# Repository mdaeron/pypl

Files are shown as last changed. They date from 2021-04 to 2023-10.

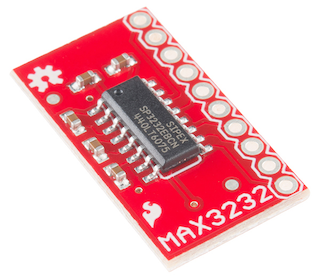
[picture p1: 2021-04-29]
pictures/sparkfun_11189.png

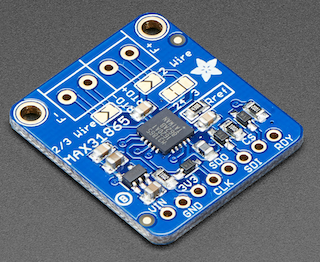
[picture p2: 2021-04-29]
pictures/adafruit_3328.png

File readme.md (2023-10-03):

# Python Prep Line (PyPL)

An open source / open hardware automation system. Originally designed for processing geochemichal samples in our stable isotope lab, but the system is flexible enough to fit many other needs.

## Core design

* Microcontrollers are not encumbered by a full OS, yet can reliably run simple tasks with low latency (μs to ms).
* PyPL uses a *pyboard*, a microcontroller running MicroPython (a full-featured Python implementation running on “bare metal”) to communicate asynchronously with sensors
(T, P, H), and actuators (stepper motors, relays, valves, heating elements...).
* The board is also connected to a full-fledged computer (e.g., a Raspberry Pi or something more expensive) which provides a GUI and logs/syncs/backups data.
* PyPL mostly uses cheap (2–20 €) breakout boards for electronic components, making most repairs plug-and-play. These boards are cheap enough that you can have spare ones, further simplifying hardware maintenance.
* All code, whether on the pyboard or on the computer, is regular Python, promoting painless
development, rapid iteration, and future-proof code.

## Documentation

Full documentation (work in progress) is [here](https://mdaeron.github.io/pypl/).

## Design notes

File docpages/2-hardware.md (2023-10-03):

# Hardware components

### Motherboard

motherboard

A custom PCB connects the [pyboard](https://store.micropython.org/product/PYBv1.1) microcontroller running [micropython](https://docs.micropython.org/en/latest/index.html) to the other electronic components, with the following inputs/outputs:

* fuse-protected DC input (typically 9-24 VDC)
* USB input/output
* 4 general-purpose inputs/outputs (GPIO labeled `X21`, `X22`, `A13`, `A14`) which may be used  for basic two-way communication with external systems (e.g, a mass spectrometer)
* 4 [D-SUB](https://en.wikipedia.org/wiki/D-subminiature) connectors for [RS-232](https://en.wikipedia.org/wiki/RS-232) communication
* 6 screw terminal groups for temperature sensors
* 38 terminal groups for DC relays, six of which can be configured for pulse-width modulation (PWM) operation and are thus well-suited for PID control
* 2 bipolar stepper motor drivers

### Pyboard

pyboard

The brains of the operation is a pyboard (v.1.1, documentation [here](https://docs.micropython.org/en/latest/pyboard/quickref.html)), based on a 168 MHz Cortex M4 CPU.

Note that the maximum total current out of the 3.3V output pins of the pyboard is 250 mA (see [here](https://forum.micropython.org/viewtopic.php?t=9329) for a more complete discussion).

### Stepper Motor Driver Boards

pololu_mp6500

We use a breakout board for the MPS MP6500 microstepping bipolar [stepper motor](https://en.wikipedia.org/wiki/Stepper_motor) driver from Pololu (docs [here](https://www.pololu.com/product/2966)). Rotating the motor is achieved by repeatedly switching the STEP pin between high and low. The motherboard is configured by default for 1/8 step resolution (pins MS1 and MS2 high, i.e. set to +3.3 V), but full steps, half-steps and quarter-steps can be selected using different MS1 and MS2 settings, either by modifying the motherboard or by tinkering with the stepper driver board.

These driver boards work well but are easy to fry when mishandled. Never connect or disconnect motor wires while the driver board is powered.

### Temperature Readings

Up to 4 independent temperature reading. Each reading may come from either:

* a [thermocouple](https://en.wikipedia.org/wiki/Thermocouple) connected to a MAX31856 chip
* a [resistance temperature detector](https://en.wikipedia.org/wiki/Resistance_thermometer) (PT1000 or PT100) connected to a MAX31865 chip

#### Thermocouple Board

* [Adafruit 3263](https://www.adafruit.com/product/3263)
* Based on MAX31856
* Configured for continuous readings and no averaging; with these settings the IC automatically measures T every 100 ms or so (82 ms in our tests) with measurement noise on the order of 0.05 °C.
* Reading the latest measurements using SPI is much faster (only about 0.14 ms when tested using a baudrate of 1e7).
* Maximum current used by each MAX31856 is 2 mA.

adafruit_3263

#### PT1000 Board

* [Adafruit 3328](https://www.adafruit.com/product/3328)
* Based on MAX31865

adafruit_3328

#### Thermocouples (type K)

* Supplier: https://www.prosensor.fr
* Part #: K4051000-2-1/TEF
* OD = 0.5 mm
* L = 1 m

#### Resistance Temperature Detectors  (PT1000)

### Heating Elements
heating_element

* Supplier: https://www.prosensor.fr
* Part #: CCHC-1/4-11/4-300-0 or CCHC-6.5-30-300-0
* 300 W at 230 VAC
* OD = 6.35 mm or 6.5 mm
* L = 31.75 mm or 30 mm

These relays are powered by 230 VAC and should thus only be switched using dedicated optocoupler relays (see below). 

### Pressure Readings

#### MicroPirani and DualTrans Vacuum/Pressure Gauges

* Part #: [MKS 925](https://www.mksinst.com/f/925-micro-pirani-vacuum-transducer)
* Part #: [MKS 910](https://www.mksinst.com/f/910-micro-pirani-vacuum-transducer)
* Communicates through an [RS-232](https://en.wikipedia.org/wiki/RS-232) serial connection

mks_910

#### RS232 / TTL Transceiver Board

Converts TTL (Transistor-Transistor Logic) signals to and from [RS-232](https://en.wikipedia.org/wiki/RS-232) signals

* [SparkFun Transceiver Breakout (BOB-11189)](https://www.sparkfun.com/products/11189)
* Based on MAX3232

sparkfun_11189

### Relays

The pyboard communicates through I2C with a GPIO expansion board based on the MCP23017 chip, providing access to 16 input or output ports. Each of these ports is connected to a power MOSFET, providing the ability to quickly switch DC power to 16 screw terminals.

#### 1.7.1 – GPIO Expansion Board

* Based on MCP23017
* All ports are pulled low (connected to ground by 10K resistors).
* As a result, all switches are off by default.

mcp23017

#### Power MOSFETSs

Used to connect screw terminals to ground safely and quickly. This means that when the MOSFET is off, whatever is connected to the screw terminals will float at a moderately high DC voltage (e.g., 24 VDC) despite being powered off, so any electrical connections should be suitably insulated.

#### Optocoupler relays

### Power Supply

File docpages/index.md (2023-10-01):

---
hide:
  - toc
---

# Python Prep Line (PyPL)

An open source, open hardware, automated preparation line for processing geochemical samples. Originally designed for CO<sub>2</sub> samples, but should handle anything which requires:

* switching relays, valves or heating elements
* monitoring temperature sensors (e.g., [thermocouples](https://en.wikipedia.org/wiki/Thermocouple) or [RTD](https://en.wikipedia.org/wiki/Resistance_thermometer) sensors)
* monitoring MKS vacuum/pressure gauges.
* controlling [stepper motors](https://en.wikipedia.org/wiki/Stepper_motor)

The user interface runs on a raspberry pi computer but this computer may be switched off or unplugged without affecting automated processes, which remain running on an independent microcontroller which handles lower-level interaction with sensors and various electronic components.

Modifying hardware configuration and sample preparation protocols is easily done using [Python](https://www.python.org) (on the computer) and [MicroPython](https://micropython.org) (on the microcontroller).

## Contributors

Originally created by [Mathieu Daëron](https://daeron.fr), with advice, contributions and feedback from Samir Kassi, Arnaud Dapoigny, and Justin Chaillot.

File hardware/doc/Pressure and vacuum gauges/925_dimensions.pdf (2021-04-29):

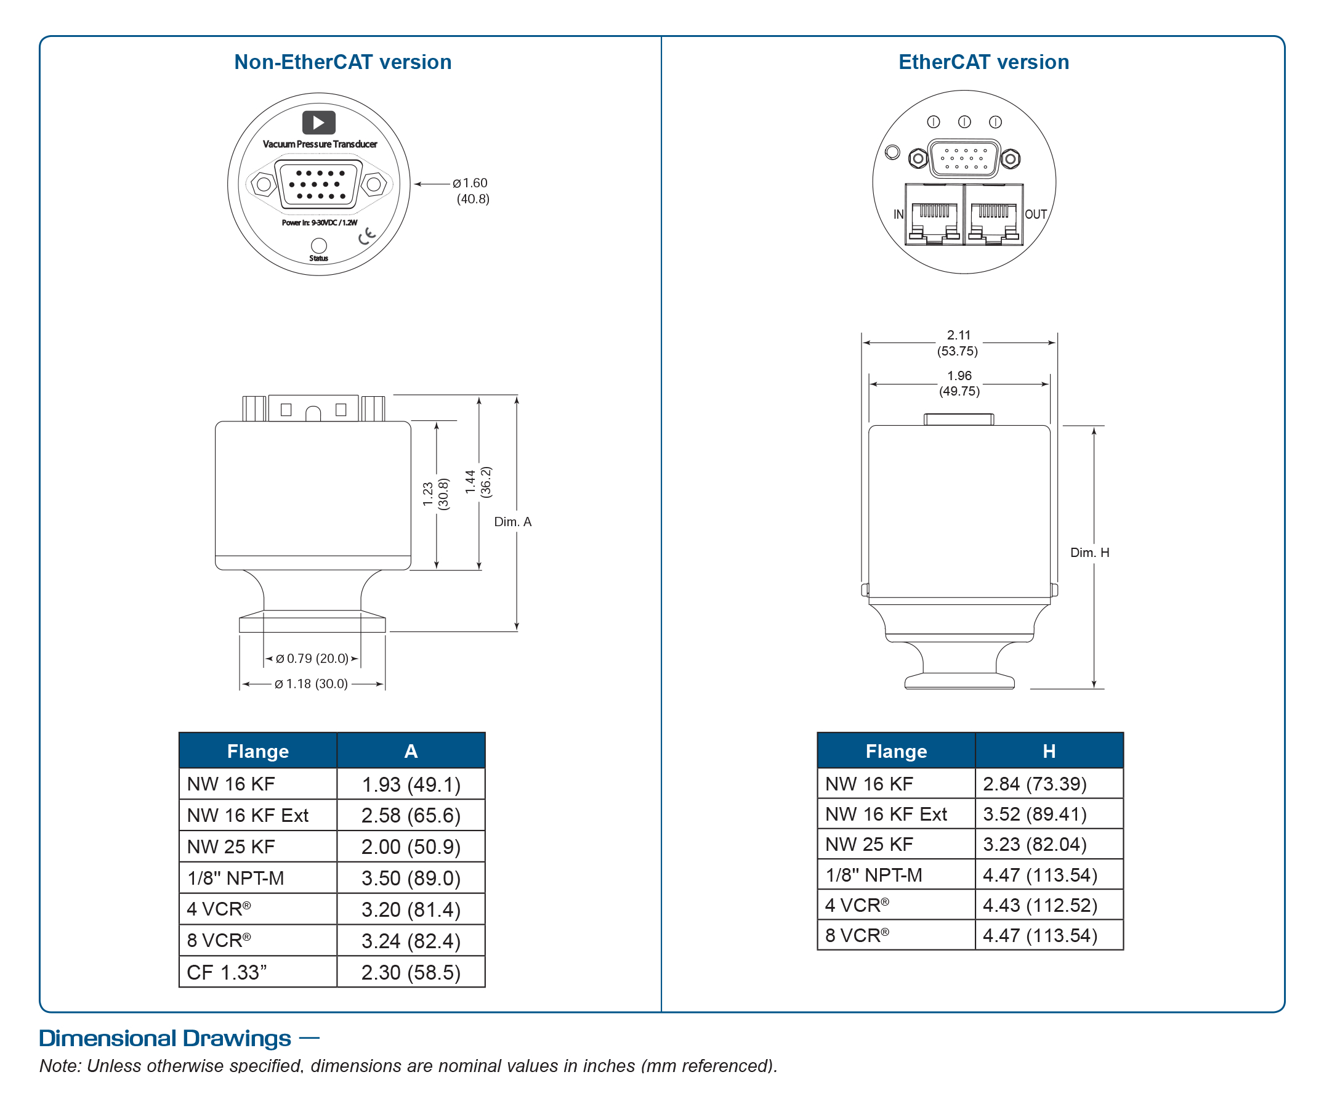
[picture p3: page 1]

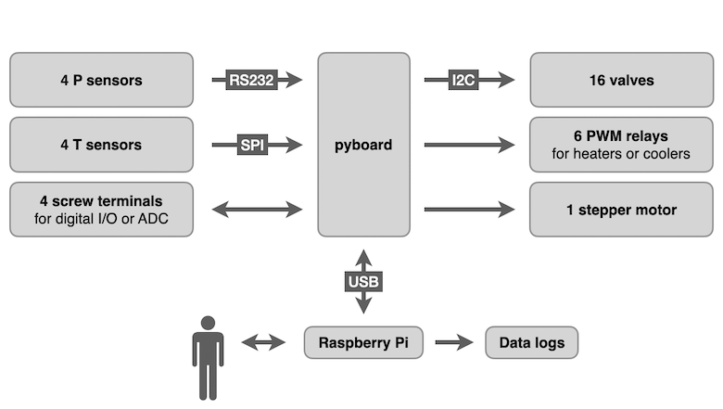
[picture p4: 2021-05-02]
pictures/pypl_schematic.png

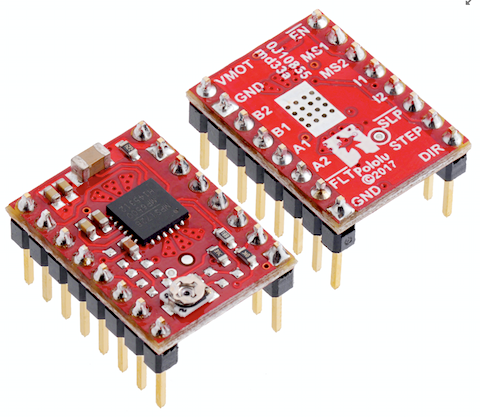
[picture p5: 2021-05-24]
pictures/pololu_mp6500.png

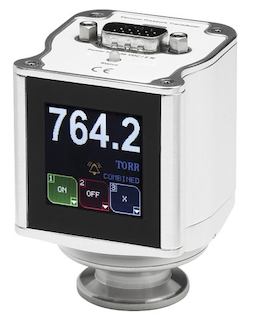
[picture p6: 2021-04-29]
pictures/mks_910.png

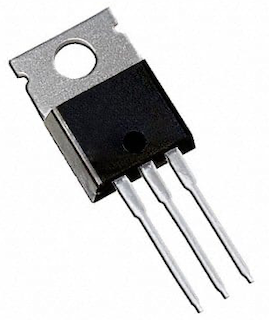
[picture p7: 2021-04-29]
pictures/mosfet.png

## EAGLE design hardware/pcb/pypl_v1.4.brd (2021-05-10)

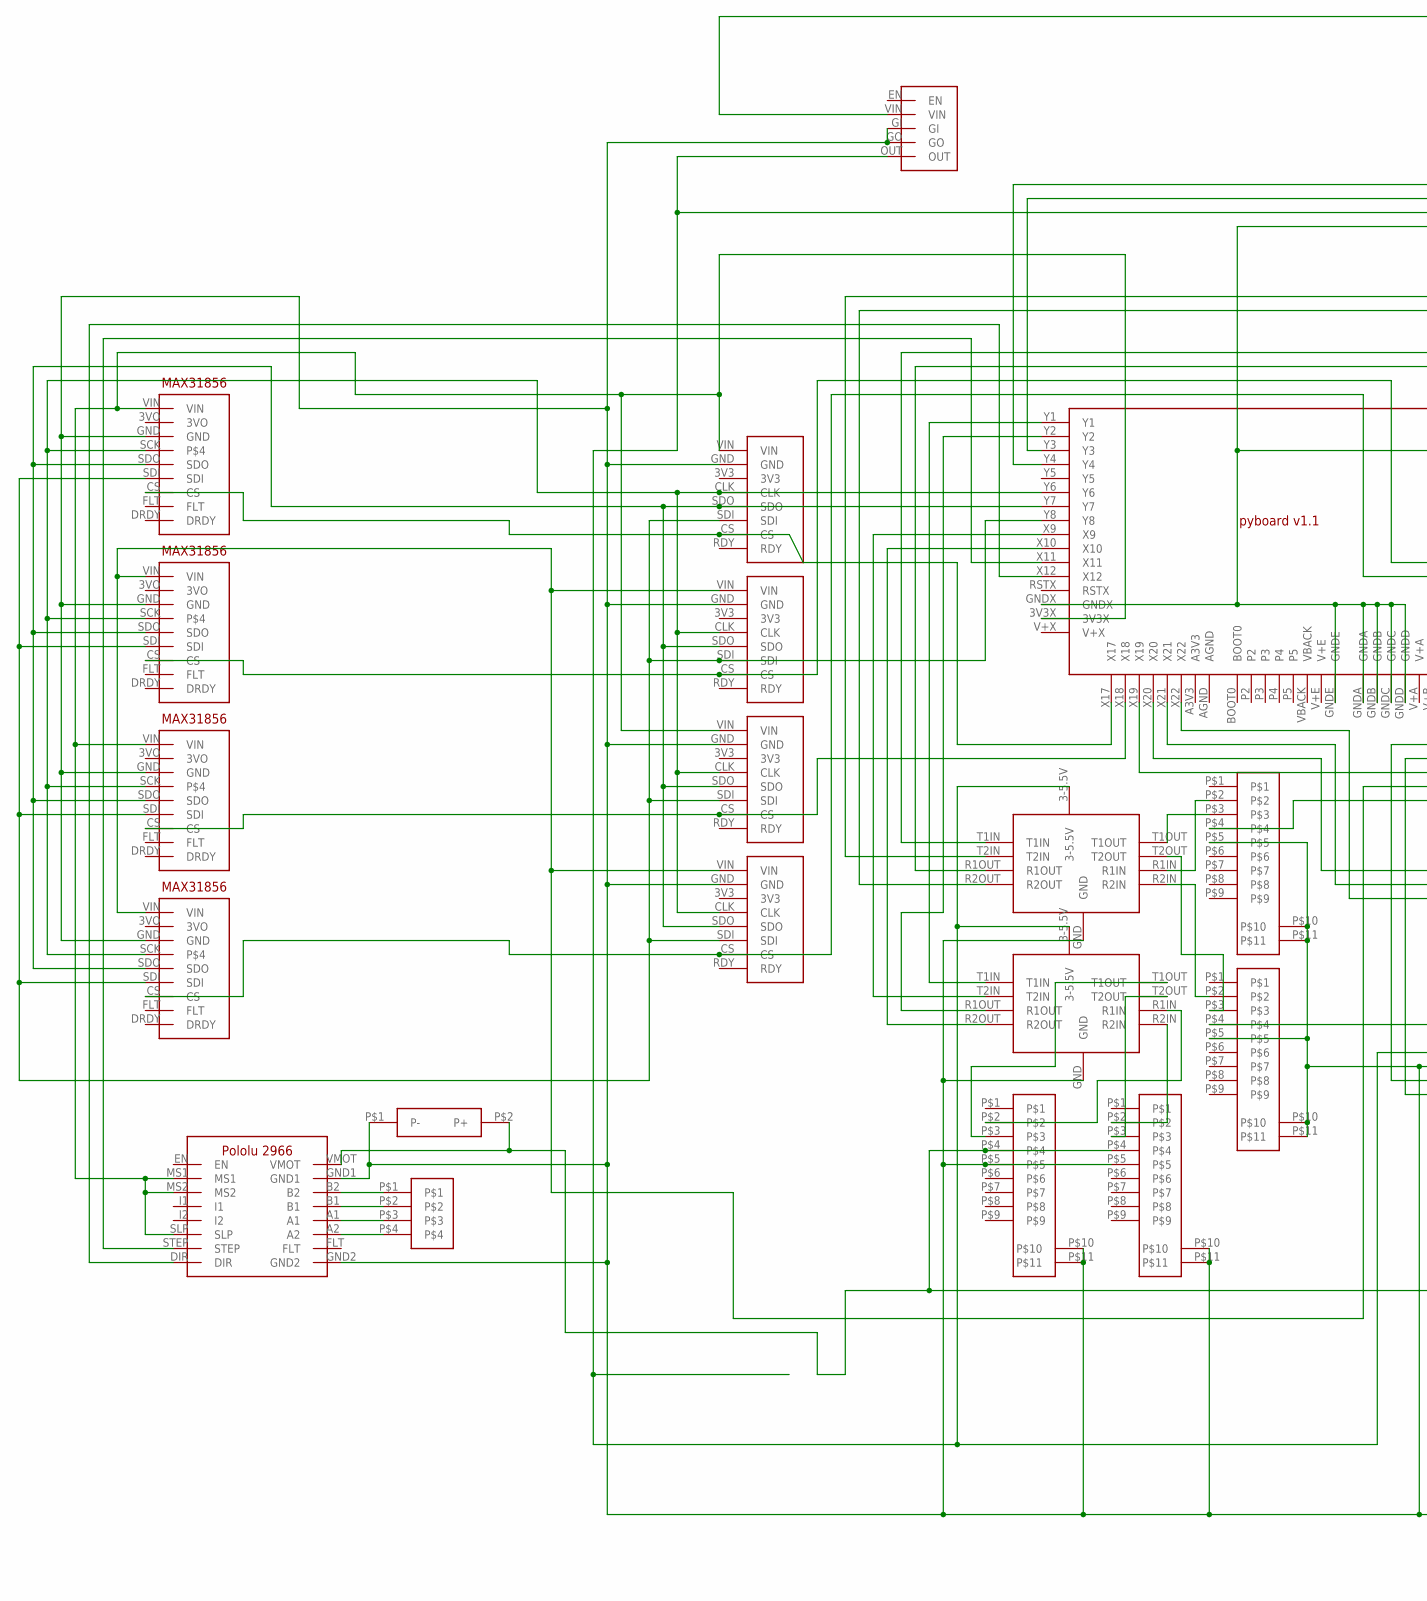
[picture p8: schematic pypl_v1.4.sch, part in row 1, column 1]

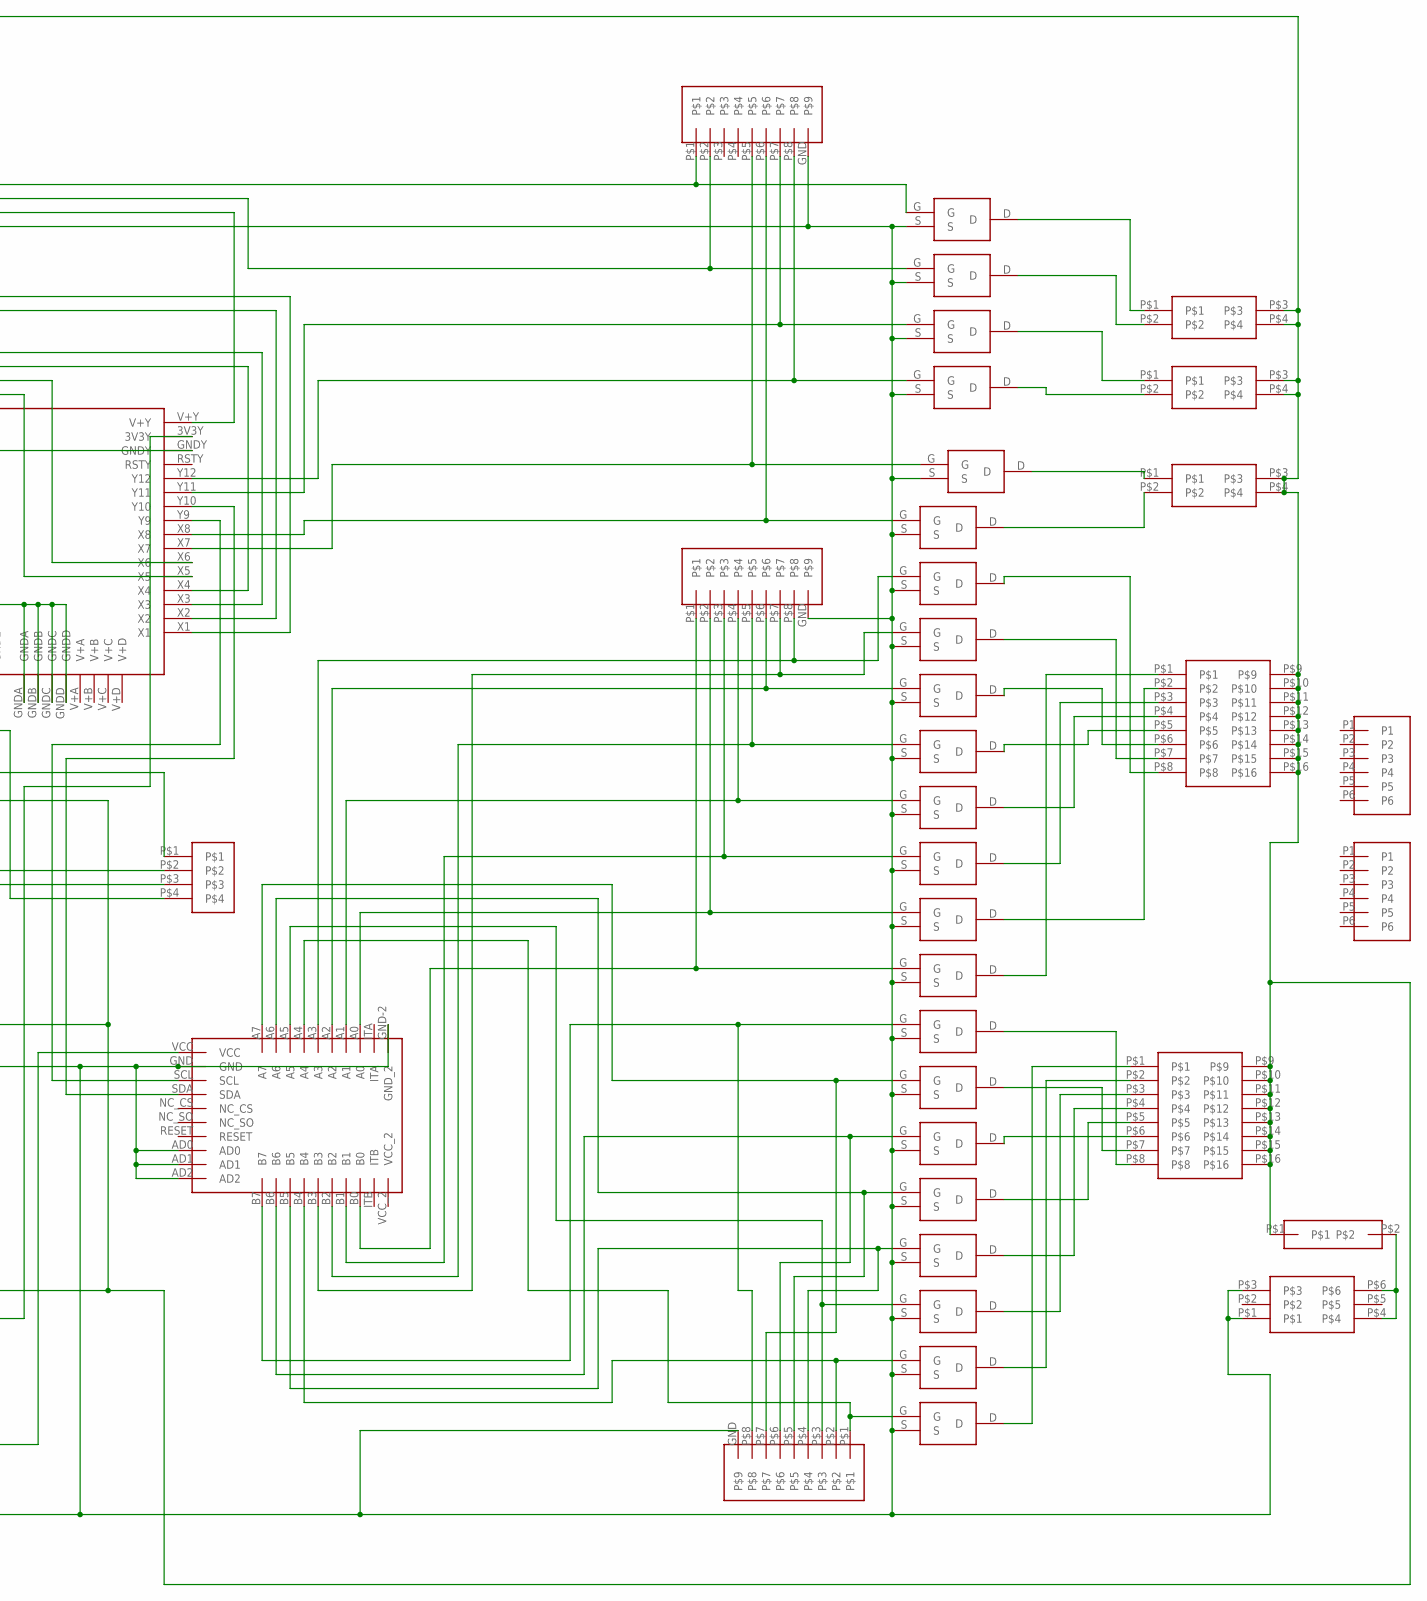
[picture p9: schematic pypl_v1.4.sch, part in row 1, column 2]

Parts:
U$1, U$23, U$25, U$26: MAX31865
U$2, U$3, U$4, U$5, U$6, U$7, U$8, U$9, U$11, U$12, U$13, U$14, U$15, U$16, U$17, U$18, U$33, U$34, U$42, U$43, U$44, U$45: IRLB8721PBF
U$10: MCP23017
U$19, U$20, U$21, U$22: DSUB-9
U$24: PYBOARD_V1.1
U$27, U$28: BORNIER_DUPLEX_X16
U$29: CAP-GOTRONIC-04936
U$30, U$46: BORNIER_1X4_2.54
U$31: PORTE-FUSIBLE
U$32: MP6500-2966
U$35, U$40, U$41: BORNIER_DUPLEX_X4
U$36, U$37: BOB-1189; BOB-11189
U$38: MOLEX_MINIFT_JR_ANGLED_X6
U$39: D24V50F5D24V50F5; D24V50F5
U$47, U$48, U$49: RESISTOR_BANK_BUSSED_X8
U$50, U$51, U$52, U$53: MAX31856
U$54, U$55: PINH06

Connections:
GND: U$1.GND, U$2.S, U$3.S, U$4.S, U$5.S, U$6.S, U$7.S, U$8.S, U$9.S, U$10.AD0, U$10.AD1, U$10.AD2, U$10.GND, U$10.GND-2 (GND_2), U$11.S, U$12.S, U$13.S, U$14.S, U$15.S, U$16.S, U$17.S, U$18.S, U$19.P$5, U$19.P$10, U$19.P$11, U$20.P$5, U$20.P$10, U$20.P$11, U$21.P$5, U$21.P$10, U$21.P$11, U$22.P$5, U$22.P$10, U$22.P$11, U$23.GND, U$24.GNDA, U$24.GNDB, U$24.GNDC, U$24.GNDD, U$24.GNDE, U$24.GNDX, U$24.GNDY, U$25.GND, U$26.GND, U$29.P$1 (P-), U$32.GND1, U$32.GND2, U$33.S, U$34.S, U$36.GND, U$37.GND, U$38.P$1, U$38.P$3, U$39.GI, U$39.GO, U$42.S, U$43.S, U$44.S, U$45.S, U$47.GND, U$48.GND, U$49.GND, U$50.GND, U$51.GND, U$52.GND, U$53.GND
unnamed: U$24.X12, U$32.DIR
unnamed: U$10.SDA, U$24.Y10
unnamed: U$10.SCL, U$24.Y9
unnamed: U$24.X4, U$36.R1OUT
unnamed: U$24.X3, U$36.T1IN
unnamed: U$24.X2, U$36.R2OUT
unnamed: U$24.X1, U$36.T2IN
unnamed: U$24.Y1, U$37.T1IN
unnamed: U$24.Y2, U$37.R1OUT
unnamed: U$24.X10, U$37.R2OUT
unnamed: U$24.X9, U$37.T2IN
unnamed: U$1.CLK, U$23.CLK, U$24.Y6, U$25.CLK, U$26.CLK, U$50.SCK, U$51.SCK, U$52.SCK, U$53.SCK
unnamed: U$1.SDO, U$23.SDO, U$24.Y7, U$25.SDO, U$26.SDO, U$50.SDO, U$51.SDO, U$52.SDO, U$53.SDO
unnamed: U$1.SDI, U$23.SDI, U$24.Y8, U$25.SDI, U$26.SDI, U$50.SDI, U$51.SDI, U$52.SDI, U$53.SDI
unnamed: U$10.A7, U$15.G, U$47.P$7
unnamed: U$4.G, U$10.B2, U$48.P$5
unnamed: U$7.G, U$10.A3, U$48.P$8
unnamed: U$6.G, U$10.B3, U$48.P$7
unnamed: U$5.G, U$10.A2, U$48.P$6
unnamed: U$3.G, U$10.A1, U$48.P$4
unnamed: U$2.G, U$10.B1, U$48.P$3
unnamed: U$8.G, U$10.A0, U$48.P$2
unnamed: U$9.G, U$10.B0, U$48.P$1
unnamed: U$10.B4, U$17.G, U$47.P$2
unnamed: U$10.B5, U$12.G, U$47.P$4
unnamed: U$10.B6, U$14.G, U$47.P$6
unnamed: U$10.B7, U$16.G, U$47.P$8
unnamed: U$10.A6, U$13.G, U$47.P$5
unnamed: U$7.D, U$28.P$8
unnamed: U$6.D, U$28.P$7
unnamed: U$5.D, U$28.P$6
unnamed: U$30.P$1, U$32.B2
unnamed: U$16.D, U$27.P$8
unnamed: U$15.D, U$27.P$7
unnamed: U$4.D, U$28.P$5
unnamed: U$3.D, U$28.P$4
unnamed: U$2.D, U$28.P$3
unnamed: U$8.D, U$28.P$2
unnamed: U$9.D, U$28.P$1
unnamed: U$14.D, U$27.P$6
unnamed: U$13.D, U$27.P$5
unnamed: U$12.D, U$27.P$4
unnamed: U$11.D, U$27.P$3
unnamed: U$17.D, U$27.P$2
unnamed: U$18.D, U$27.P$1
unnamed: U$24.X19, U$46.P$1
unnamed: U$40.P$2, U$42.D
unnamed: U$10.VCC, U$24.V+Y, U$36.3-5.5V, U$37.3-5.5V, U$39.OUT
unnamed: U$31.P$2, U$38.P$4, U$38.P$6
unnamed: U$24.X6, U$26.CS, U$51.CS
unnamed: U$1.CS, U$24.X18, U$52.CS
unnamed: U$24.X17, U$25.CS, U$50.CS
unnamed: U$24.X7, U$34.G, U$49.P$5
unnamed: U$24.X8, U$33.G, U$49.P$6
unnamed: U$33.D, U$35.P$2
unnamed: U$34.D, U$35.P$1
unnamed: U$30.P$2, U$32.B1
unnamed: U$30.P$3, U$32.A1
unnamed: U$30.P$4, U$32.A2
unnamed: U$19.P$2, U$36.R1IN
unnamed: U$20.P$2, U$36.R2IN
unnamed: U$40.P$1, U$43.D
unnamed: U$21.P$2, U$37.R2IN
unnamed: U$22.P$2, U$37.R1IN
unnamed: U$19.P$3, U$36.T1OUT
unnamed: U$20.P$3, U$36.T2OUT
unnamed: U$22.P$3, U$37.T1OUT
unnamed: U$21.P$3, U$37.T2OUT
unnamed: U$1.VIN, U$24.3V3X, U$25.VIN, U$32.MS1, U$32.MS2, U$32.SLP, U$50.VIN, U$52.VIN
unnamed: U$23.CS, U$24.X5, U$53.CS
unnamed: U$41.P$2, U$44.D
unnamed: U$23.VIN, U$24.3V3Y, U$26.VIN, U$51.VIN, U$53.VIN
unnamed: U$19.P$4, U$20.P$4, U$21.P$4, U$22.P$4, U$27.P$9, U$27.P$10, U$27.P$11, U$27.P$12, U$27.P$13, U$27.P$14, U$27.P$15, U$27.P$16, U$28.P$9, U$28.P$10, U$28.P$11, U$28.P$12, U$28.P$13, U$28.P$14, U$28.P$15, U$28.P$16, U$29.P$2 (P+), U$31.P$1, U$32.VMOT, U$35.P$3, U$35.P$4, U$39.VIN, U$40.P$3, U$40.P$4, U$41.P$3, U$41.P$4
unnamed: U$24.X20, U$46.P$2
unnamed: U$24.X21, U$46.P$3
unnamed: U$24.X22, U$46.P$4
unnamed: U$24.X11, U$32.STEP
unnamed: U$10.A5, U$11.G, U$47.P$3
unnamed: U$41.P$1, U$45.D
unnamed: U$24.Y11, U$43.G, U$49.P$7
unnamed: U$24.Y12, U$42.G, U$49.P$8
unnamed: U$24.Y3, U$44.G, U$49.P$2
unnamed: U$24.Y4, U$45.G, U$49.P$1
unnamed: U$10.A4, U$18.G, U$47.P$1

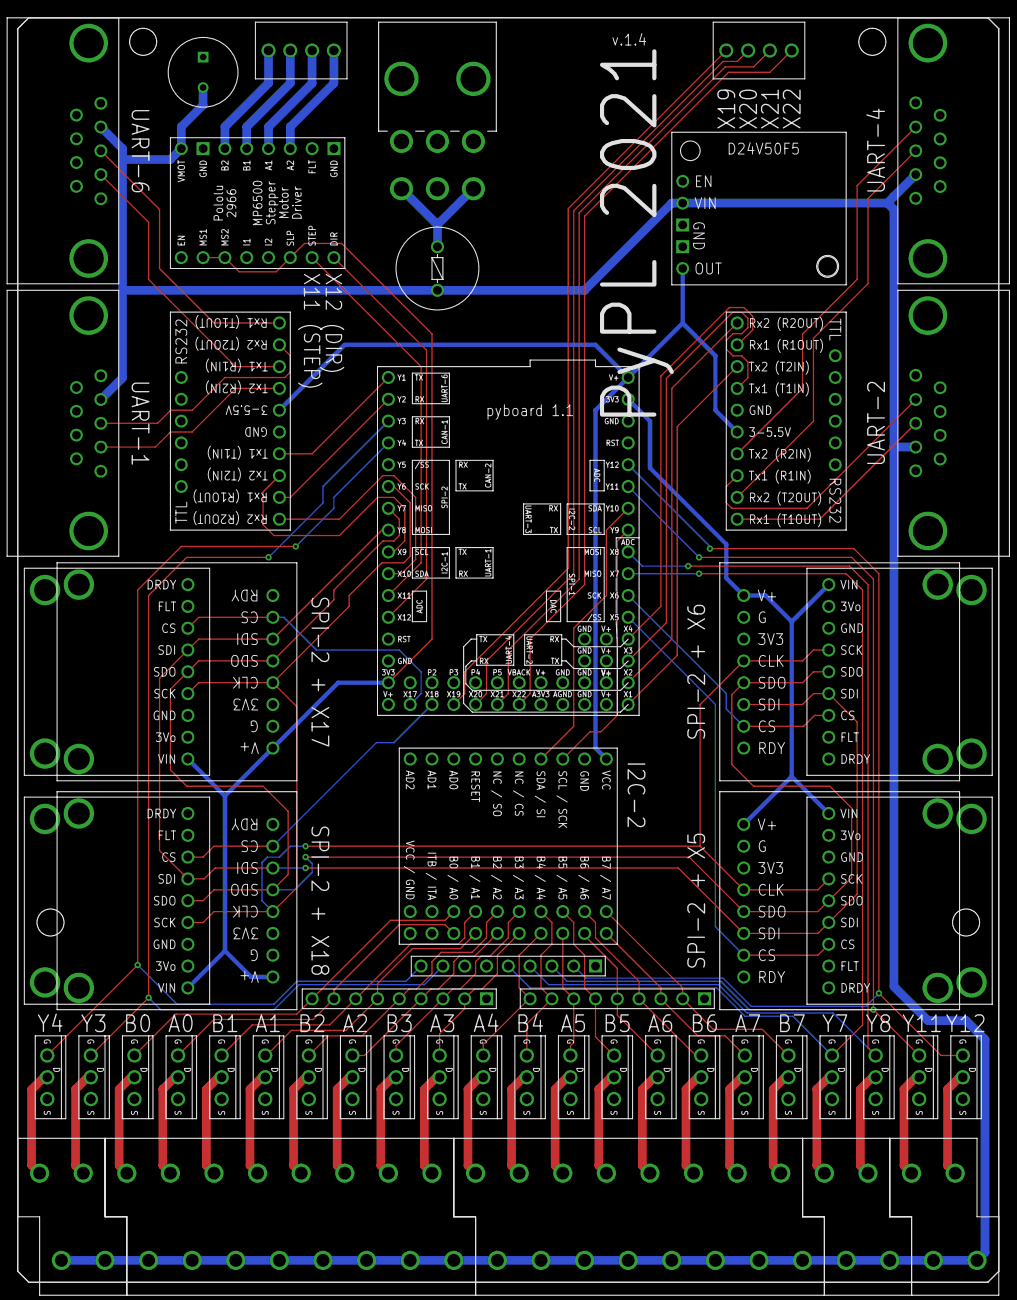
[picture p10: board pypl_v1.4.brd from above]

Board: 2 copper layers, 114.3 x 147.3 mm, 55 parts (0 on the bottom side), 85 nets.

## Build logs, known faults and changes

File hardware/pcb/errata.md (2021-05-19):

* PWM relays "X7" and "X8" are mislabeled as "Y7" and "Y8".

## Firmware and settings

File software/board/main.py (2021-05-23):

print('-- Booting uPyPL board --')

import pyb, uasyncio, utime, machine, math
from sys import print_exception
from MKSGauge import MKSGauge
from max31865 import PT1000
from max31856 import MAX31856
from mcp23017 import MCP23017
from timing import timing
from stepper import Stepper
from thermostat import _PWM, Thermostat, PID
from heartbeat import Heartbeat

class Valve():

	def __init__(self, gpio):
		self.gpio = gpio
	
	def state(self):
		return self.gpio.value()

	def open(self):
		self.gpio.value(1)

	def close(self):
		self.gpio.value(0)

	def toggle(self):
		self.gpio.value(1 - self.gpio.value())


class DummySensor():
	def __init__(self):
		self.T = lambda : 0.
		self.P = 0.
		self.v = 0
	
	def value(self, *args):
		if args:
			self.v = args[0]
		else:
			return(self.v)

	def toggle(self):
		self.value(1 - self.value())


class PyPL():

	def __init__(self, cycle = 0.01, separators = '\r;', status_cycle = 0.1, DEBUG = False):
		self.DEBUG = DEBUG
		self.heartbeat = Heartbeat()
		self.serial = pyb.USB_VCP()
		self.cycle = cycle
		self.clock = 0
		self.rbuf = ''
		self.sep1, self.sep2 = separators
		self.instructions = []
		self.status_cycle = status_cycle
		self.task_blink = None
		self.rtc = pyb.RTC()
# 		self.accel = pyb.Accel()


		self.stepper = Stepper(dir_pin = 'B4') # use B4 because X12 is fried on my development pyboard


		self.P1 = DummySensor()
		self.P2 = DummySensor()
		self.P3 = DummySensor()
		self.P4 = DummySensor()

		self.T1 = DummySensor()
		self.T2 = DummySensor()
		self.T3 = DummySensor()
		self.T4 = DummySensor()

		self.V1 = Valve(DummySensor())
		self.V2 = Valve(DummySensor())
		self.V3 = Valve(DummySensor())
		self.V4 = Valve(DummySensor())
		self.V5 = Valve(DummySensor())
		self.V6 = Valve(DummySensor())
		self.V7 = Valve(DummySensor())
		self.V8 = Valve(DummySensor())
		self.V9 = Valve(DummySensor())
		self.V10 = Valve(DummySensor())
		self.V11 = Valve(DummySensor())
		self.V12 = Valve(DummySensor())
		self.V13 = Valve(DummySensor())
		self.V14 = Valve(DummySensor())
		self.V15 = Valve(DummySensor())
		self.V16 = Valve(DummySensor())

		self.P1 = MKSGauge(6)
		self.P2 = MKSGauge(4)
		self.P3 = MKSGauge(1)
		self.P4 = MKSGauge(2)

		try:
			self.i2c = machine.I2C(2)
			self.gpio = MCP23017(self.i2c, 0x20)
			self.gpio.mode = 0x0000 # configure all pins as outputs
			self.gpio.gpio = 0x0000 # set all pins to low

			self.V1 = Valve(self.gpio[0])
			self.V2 = Valve(self.gpio[1])
			self.V3 = Valve(self.gpio[2])
			self.V4 = Valve(self.gpio[3])
			self.V5 = Valve(self.gpio[4])
			self.V6 = Valve(self.gpio[5])
			self.V7 = Valve(self.gpio[6])
			self.V8 = Valve(self.gpio[7])
			self.V9 = Valve(self.gpio[8])
			self.V10 = Valve(self.gpio[9])
			self.V11 = Valve(self.gpio[10])
			self.V12 = Valve(self.gpio[11])
			self.V13 = Valve(self.gpio[12])
			self.V14 = Valve(self.gpio[13])
			self.V15 = Valve(self.gpio[14])
			self.V16 = Valve(self.gpio[15])

		except OSError:
			pass




		self.spi = pyb.SPI(2, mode = pyb.SPI.MASTER, baudrate = 10**7, phase = 1)
		self.T1 = MAX31856(self.spi, pyb.Pin('X5', pyb.Pin.OUT))
		self.T2 = MAX31856(self.spi, pyb.Pin('X6', pyb.Pin.OUT))
		self.T3 = MAX31856(self.spi, pyb.Pin('X17', pyb.Pin.OUT))
		self.T4 = MAX31856(self.spi, pyb.Pin('X18', pyb.Pin.OUT))

		self.hPWM_1 = _PWM('Y3')
		self.cPWM_1 = _PWM('Y4')
		self.hPWM_2 = _PWM('X7')
		self.cPWM_2 = _PWM('X8')
		self.hPWM_3 = _PWM('Y12')
		self.cPWM_3 = _PWM('Y11')

		self.hPID_1 = PID(
			self.T1.T,
			self.hPWM_1.output,
			set_point = 40,
			Kp = 1., Ki = 0.03, Kd = 0., I_min = -6, I_max = 6, cycle = 1)

		self.cPID_1 = PID(
			self.T1.T,
			self.cPWM_1.output,
			set_point = -80,
			Kp = 1., Ki = 0.03, Kd = 0., I_min = -6, I_max = 6, cycle = 1, invert = True)

		self.hPID_2 = PID(
			self.T2.T,
			self.hPWM_2.output,
			set_point = 40,
			Kp = 1., Ki = 0.03, Kd = 0., I_min = -6, I_max = 6, cycle = 1)

		self.cPID_2 = PID(
			self.T2.T,
			self.cPWM_2.output,
			set_point = -80,
			Kp = 1., Ki = 0.03, Kd = 0., I_min = -6, I_max = 6, cycle = 1, invert = True)

		self.hPID_3 = PID(
			self.T3.T,
			self.hPWM_3.output,
			set_point = 40,
			Kp = 1., Ki = 0.03, Kd = 0., I_min = -6, I_max = 6, cycle = 1)

		self.cPID_3 = PID(
			self.T3.T,
			self.cPWM_3.output,
			set_point = -80,
			Kp = 1., Ki = 0.03, Kd = 0., I_min = -6, I_max = 6, cycle = 1, invert = True)

		self.TS1 = Thermostat(self.hPID_1, self.cPID_1)
		self.TS2 = Thermostat(self.hPID_2, self.cPID_2)
		self.TS3 = Thermostat(self.hPID_3, self.cPID_3)
		
		self.start_blink_dialog = 1
		self.stop_blink_dialog = 0
		self.confirm_stop_blink_dialog = 0
		self.undo_stop_blink_dialog = 0

	def send(self, txt):
		self.serial.write(txt + self.sep1)

	def echo(self, txt):
		self.send('echo' + self.sep2 + txt)

	def echolog(self, txt):
		self.send('echolog' + self.sep2 + txt)

	def zero_clock(self):
		self.send('zero_clock')

	def timestamped_echo(self, txt):
		self.send('timestamp')
		self.echolog(txt)
	
	def newline(self):
		self.send('newline')
	
	def clearline(self):
		self.send('clearline')	

	def datetime(self):
		now = self.rtc.datetime()
		s = now[6] + (255-now[7])/255
		return ('NOW=s%04d-%02d-%02d' % now[:3]) + (' %02d:%02d:' % now[4:6]) + ('%06.3f' % s)
	
	def set_rtc(self, t):
		self.rtc.datetime(t) # t must be a tuple of ints: (year, month, day, weekday, hours, minutes, seconds, subseconds)

	def send_status(self):
		self.send(
			'status'
			+ self.sep2 + self.datetime()
# 			+ self.sep2 + 'x=f%.2f' % (self.accel.x() / 32)
# 			+ self.sep2 + 'y=f%.2f' % (self.accel.y() / 32)
# 			+ self.sep2 + 'z=f%.2f' % (self.accel.z() / 32)
			+ self.sep2 + ('P1=n' if self.P1.P is None else ('P1=f%.4e' % self.P1.P))
			+ self.sep2 + ('P2=n' if self.P2.P is None else ('P2=f%.4e' % self.P2.P))
			+ self.sep2 + ('P3=n' if self.P3.P is None else ('P3=f%.4e' % self.P3.P))
			+ self.sep2 + ('P4=n' if self.P4.P is None else ('P4=f%.4e' % self.P4.P))
			+ self.sep2 + ('T1=n' if self.T1.T() is None else ('T1=f%.2f' % self.T1.T()))
			+ self.sep2 + ('T2=n' if self.T2.T() is None else ('T2=f%.2f' % self.T2.T()))
			+ self.sep2 + ('T3=n' if self.T3.T() is None else ('T3=f%.2f' % self.T3.T()))
			+ self.sep2 + ('T4=n' if self.T4.T() is None else ('T4=f%.2f' % self.T4.T()))
			+ self.sep2 + 'V1=b%s' % self.V1.state()
			+ self.sep2 + 'V2=b%s' % self.V2.state()
			+ self.sep2 + 'V3=b%s' % self.V3.state()
			+ self.sep2 + 'V4=b%s' % self.V4.state()
			+ self.sep2 + 'V5=b%s' % self.V5.state()
			+ self.sep2 + 'V6=b%s' % self.V6.state()
			+ self.sep2 + 'V7=b%s' % self.V7.state()
			+ self.sep2 + 'V8=b%s' % self.V8.state()
			+ self.sep2 + 'V9=b%s' % self.V9.state()
			+ self.sep2 + 'V10=b%s' % self.V10.state()
			+ self.sep2 + 'V11=b%s' % self.V11.state()
			+ self.sep2 + 'V12=b%s' % self.V12.state()
			+ self.sep2 + 'V13=b%s' % self.V13.state()
			+ self.sep2 + 'V14=b%s' % self.V14.state()
			+ self.sep2 + 'V15=b%s' % self.V15.state()
			+ self.sep2 + 'V16=b%s' % self.V16.state()
			+ self.sep2 + 'hPWM1=b%s' % self.hPWM_1.state()
			+ self.sep2 + 'cPWM1=b%s' % self.cPWM_1.state()
			+ self.sep2 + 'hPWM2=b%s' % self.hPWM_2.state()
			+ self.sep2 + 'cPWM2=b%s' % self.cPWM_2.state()
			+ self.sep2 + 'hPWM3=b%s' % self.hPWM_3.state()
			+ self.sep2 + 'cPWM3=b%s' % self.cPWM_3.state()
			+ self.sep2 + ('TS1=n' if self.TS1.target is None else ('TS1=f%.0f' % self.TS1.target))
			+ self.sep2 + ('TS2=n' if self.TS2.target is None else ('TS2=f%.0f' % self.TS2.target))
			+ self.sep2 + ('TS3=n' if self.TS3.target is None else ('TS3=f%.0f' % self.TS3.target))
# 			+ self.sep2 + 'start_blink_dialog=b%s' % self.start_blink_dialog
# 			+ self.sep2 + 'stop_blink_dialog=b%s' % self.stop_blink_dialog
# 			+ self.sep2 + 'confirm_stop_blink_dialog=b%s' % self.confirm_stop_blink_dialog
# 			+ self.sep2 + 'undo_stop_blink_dialog=b%s' % self.undo_stop_blink_dialog
# 			+ self.sep2 + 'DEBUG=s%s %s' % (repr(self.stepper.position), repr(self.stepper.target))
			)

	async def status_loop(self):
		while True:
			await uasyncio.sleep(self.status_cycle)
			self.send_status()
			

	async def loop(self):
		while True:
			self.clock = (self.clock + 1) % 100
			await uasyncio.sleep(self.cycle)

			# print debug info
			if self.DEBUG and self.clock == 0:
				self.echo('Stepper position: %.0f' % self.stepper.position)

			# read instructions from serial
			while self.serial.any():
				self.rbuf += self.serial.read().decode()
			if self.rbuf:
				self.instructions += self.rbuf.split(self.sep1)
				self.rbuf = self.instructions.pop()

			# process instructions
			while self.instructions:
				i = self.instructions.pop(0)
				if len(i):
					if i[0] == '@':
						eval(i[1:])

# 				if i[0] == 'toggle':
# 					self.__dict__[i[1]].toggle()
# 				elif i[0] == 'open':
# 					self.__dict__[i[1]].open()
# 				elif i[0] == 'close':
# 					self.__dict__[i[1]].close()
# 				elif i[0] == 'start':
# 					self.__dict__[i[1]].start()
# 				elif i[0] == 'start_thermostat':
# 					self.__dict__[i[1]].start(float(i[2]))
# 				elif i[0] == 'stop':
# 					self.__dict__[i[1]].stop()
# 				elif i[0] == 'start_blink':
# 					self.task_blink = uasyncio.create_task(self.blink())
# 				elif i[0] == 'stop_blink':
# 					self.confirm_stop_blink_dialog = 1
# 					self.undo_stop_blink_dialog = 1
# 				elif i[0] == 'confirm_stop_blink':
# 					self.confirm_stop_blink_dialog = 0
# 					self.undo_stop_blink_dialog = 0
# 					self.task_blink.cancel()
# 				elif i[0] == 'undo_stop_blink':
# 					self.confirm_stop_blink_dialog = 0
# 					self.undo_stop_blink_dialog = 0
# 				elif i[0] == 'stepper':
# 					if i[1] == 'fwd':
# 						self.stepper.fwd()
# 					elif i[1] == 'bwd':
# 						self.stepper.bwd()
# 				elif i[0] == 'set_rtc':
# 					self.rtc.datetime(tuple([int(e) for e in i[1:]]))
					
	async def countdown(self, t, txt = ' remaining...', dt = 1):
		clearline = False
		while t :
			if clearline:
				self.clearline()
			else:
				clearline = True
			self.echo('%02d:%02d%s' % (t // 60, t % 60, txt))
			await uasyncio.sleep(1)
			t -= dt
		self.clearline()

	def start(self):
		with open('errorlog.txt', 'w') as f:
			f.write('')
		uasyncio.create_task(self.status_loop())
		uasyncio.run(self.loop())

	def standby(self):
		self.V1.close()
		self.V2.close()
		self.V3.open()
		self.V4.open()
		self.V5.open()
		self.V6.open()
		self.V7.open()
		self.V8.close()
		self.V9.open()
		self.V10.open()
		self.V11.close()
		self.V12.open()
# 		self.V13.close()
# 		self.V14.close()
# 		self.V15.close()
# 		self.V16.close()
		self.TS1.start(40)
		self.TS2.start(40)
		self.TS3.start(40)

	async def blink(self):
		try:
			self.send('start_prep')
			self.start_blink_dialog = 0
			self.stop_blink_dialog = 1
			self.zero_clock()
			self.newline()
			self.timestamped_echo('Start blinking protocol')
			self.V1.close()
			self.V2.close()
			self.V3.close()
			self.timestamped_echo('Valves closed')
			await self.countdown(5)
			self.V1.open()
			self.V2.open()
			self.V3.open()
			self.timestamped_echo('Valves open')
			await self.countdown(5)
			self.timestamped_echo('End of blinking protocol')
			self.newline()
			self.stop_blink_dialog = 0
			self.start_blink_dialog = 1
		except uasyncio.CancelledError:
			self.newline()
			self.timestamped_echo('!!! Blinking protocol cancelled')
			self.newline()
			self.stop_blink_dialog = 0
			self.start_blink_dialog = 1
		self.send('end_prep')
		

if __name__ == '__main__':

	pyb.LED(2).on()
	try:
		pypl = PyPL(DEBUG = False)	
		pyb.LED(2).off()
		pypl.start()
	except Exception as e:
		print_exception(e, open('errorlog.txt', 'w'))
		pyb.LED(2).off()
		pyb.LED(3).off()
		while True:
			pyb.LED(1).toggle()
			utime.sleep(.2)

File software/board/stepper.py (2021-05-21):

import pyb, uasyncio

class Stepper():

	def __init__(self, timer = 12, stp_pin = 'X11', dir_pin = 'X12', fwd_dir = 0, resolution = 3200, inc_length = 3200//4, inc_duration = 1., start = True):
		self.stp_pin = pyb.Pin(stp_pin, pyb.Pin.OUT_PP)
		self.dir_pin = pyb.Pin(dir_pin, pyb.Pin.OUT_PP)
		self.fwd_dir = fwd_dir
		self.resolution = resolution
		self.inc_length = inc_length
		self.inc_duration = inc_duration
		self.timer = pyb.Timer(timer, freq = 2 * self.inc_length / self.inc_duration)
		self.stp_pin.value(0)
		self.dir_pin.value(self.fwd_dir)
		self.position = 0
		self.target = 0
		if start:
			self.timer.callback(self.loop)

	def start(self):
		self.timer.callback(self.loop)

	def stop(self):
		self.timer.callback(None)

	def loop(self, t):
		if self.position != self.target:
			if self.target > self.position:
				self.dir_pin.value(self.fwd_dir)
			else:
				self.dir_pin.value(1-self.fwd_dir)
			self.stp_pin.value(1 - self.stp_pin.value())
			if self.stp_pin.value():
				if self.dir_pin.value() == self.fwd_dir:
					self.position = self.position + 1
				else:
					self.position = self.position - 1

	def fwd(self, n = 1):
		self.target = self.target + self.inc_length * n

	def bwd(self, n = 1):
		self.target = self.target - self.inc_length * n

	def microfwd(self, n = 1):
		self.target = self.target + n

	def microbwd(self, n = 1):
		self.target = self.target - n

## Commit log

2020-12-21 Add board code, 5V supply doc and pcb files
    [pypl.brd, pypl.sch]
2020-12-25 Add MAX31855 thermocouple board
2020-12-28 Add liveplot.py; further accelerate NIST correction to max31855.py
    [main.py]
2020-12-31 Read datetime objects in liveplot; corrected PyPL_GUI.set_rtc()
    [main.py]
2021-01-08 Add Stepper(), Heartbeat() and DummySensor()
2021-01-14 Better handling of missing sensors
    [main.py]
2021-05-02 Add general schematic and update Eagle files
    [pypl.brd, pypl.sch]
2021-05-02 Add general schematic
2021-05-10 Add Max31856 and gui changes
    [pypl_v1.4.brd, pypl_v1.4.sch]
2021-05-19 Use eval() to send instructions; add on-board error logging
    [main.py]
2021-05-21 Stepper now uses interrupts rather than uasyncio
2021-05-22 Add method to relay commands directly to the board from terminal
2021-05-22 Add command buttons
2021-05-23 Add acid pump and acid gauge
2021-05-24 Add vacuum indicators to tubes in GUI
